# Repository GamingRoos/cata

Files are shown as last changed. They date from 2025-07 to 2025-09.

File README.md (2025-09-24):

# Cata Keyboard

Cata is a 34 key ortholinear keyboard, powered by a [Waveshare RP2040-Zero](https://www.waveshare.com/rp2040-zero.htm).

It uses [Gateron KS-33 Low Profile 3.0 keyswitches](https://nuphy.com/products/gateron-low-profile-3-0-switches) with 19mm x 19mm spacing.

The PCB design is akin to the [Sha Keyboard](https://github.com/skarrmann/sha), but with fewer keys and different keyswitches.

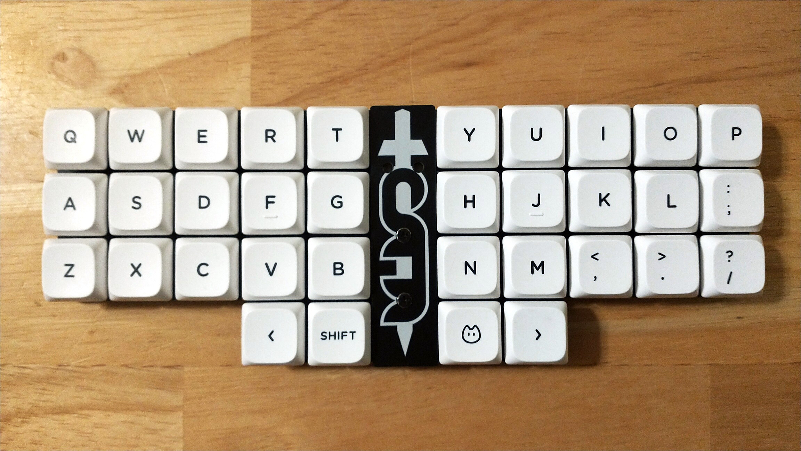
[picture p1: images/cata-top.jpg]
Cata complete build top photo

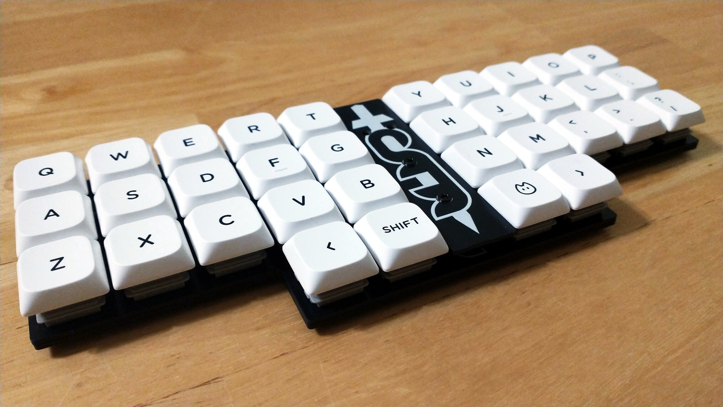
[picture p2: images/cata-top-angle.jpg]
Cata complete build top angle photo

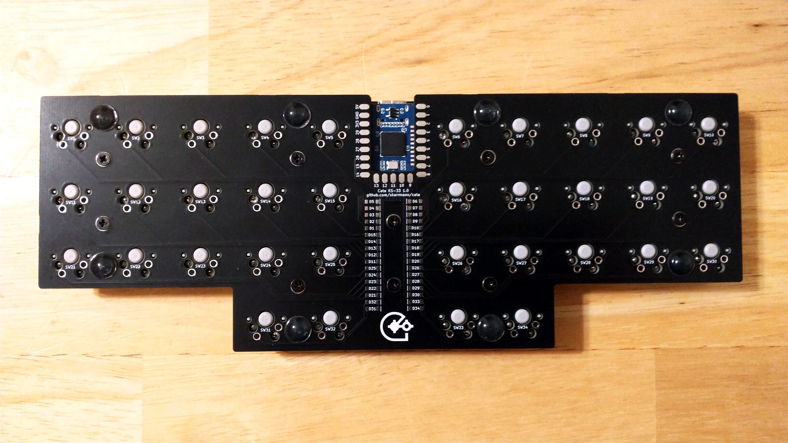
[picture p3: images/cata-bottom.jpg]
Cata complete build bottom photo

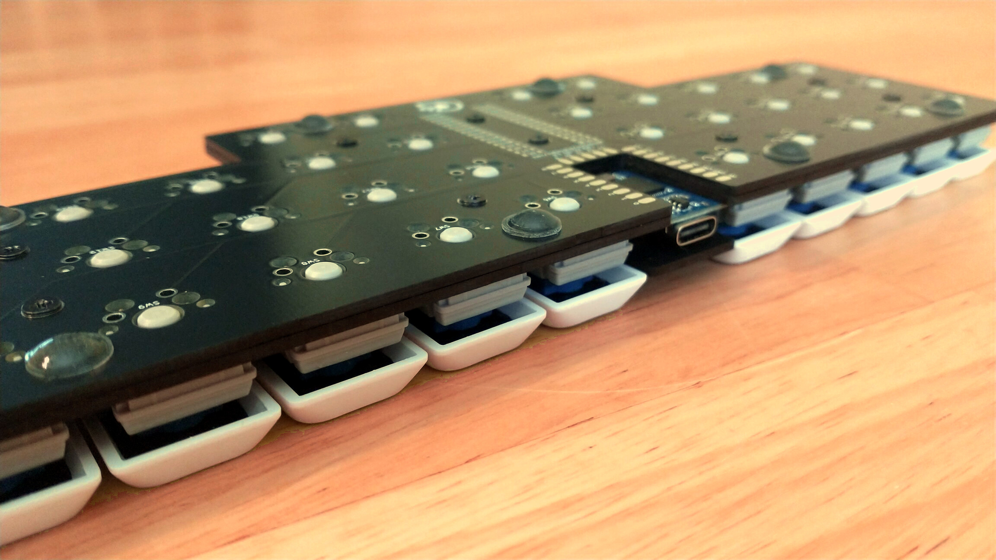
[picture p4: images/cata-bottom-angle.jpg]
Cata complete build bottom angle photo


## Project structure

* [`gerbers`](gerbers): Gerber files for PCB manufacturing
* [`graphics`](graphics): Source assets for PCB silkscreen
* [`kicad`](kicad): KiCad project files (schematics and PCB designs)
* [`kicad-libraries`](kicad-libraries): KiCad components and footprints
* [`images`](images): Images for project documentation

## PCBs

**Each build uses two copies of the main PCB and one copy of the top plate PCB.**

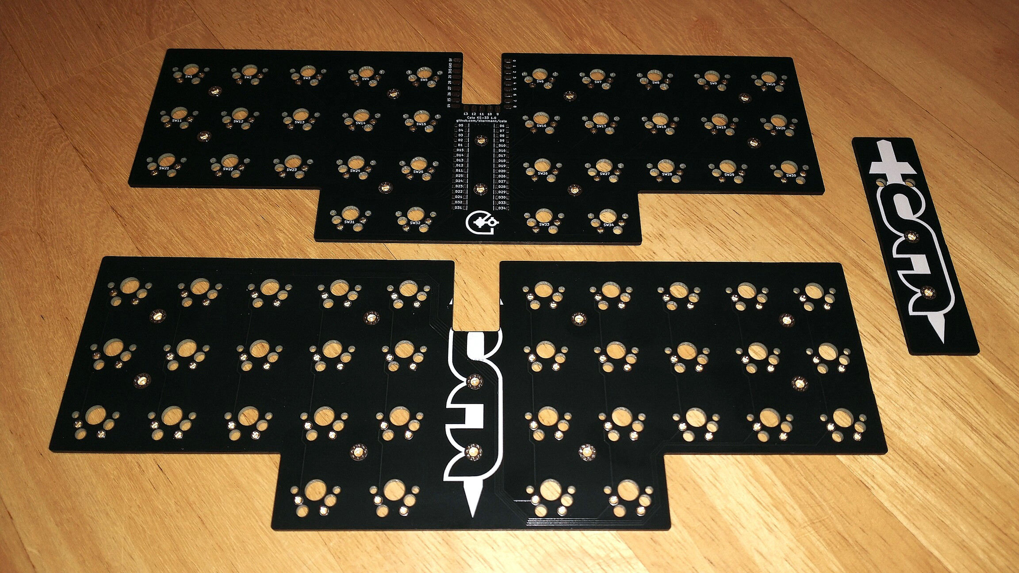
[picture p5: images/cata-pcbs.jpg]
Cata PCBs photo


The main PCB is used as the logical PCB. A second copy of the main PCB is used a bottom plate, by flipping it the long way and screwing it directly to the logical PCB.

The plate PCB cover the dev board and diodes. It has cutouts which fit the boot and reset buttons on the dev board.

## Keyboard firmware

* KMK
    * Setup instructions and basic configuration is in this repo: [`firmware/kmk`](firmware/kmk)
* [QMK](https://github.com/qmk/qmk_firmware/tree/master/keyboards/cata)
* QMK/VIAL VIAL configs here: [`firmware/vial`](firmware/vial)
## Bill of materials

Part | Purpose | Quantity | Notes
---- | ------- | -------- | ---------
Main PCB  | logical PCB, bottom plate | 2 | Send Gerber zip files to [JLCPCB](https://jlcpcb.com/)
Top plate PCB  | cover dev board and diodes  | 1 | 
Waveshare RP2040-Zero | Microcontroller board | 1 |
1N4148 SOD-123 | Diodes for keyboard row-column matrix | 34 |
Gateron KS-33 Low Profile 3.0 Keyswitches |  | 34 | [Several options available from Nuphy](https://nuphy.com/products/gateron-low-profile-3-0-switches)
MX Low Profile Keycaps | | 34 | Use low profile keycaps which fit 19mm x 19mm spacing
M2 5mm screws | Screws PCBs together | 12 |
M2 6mm spacers | Spacers between logical PCB and top plates | 2 |
M2 nuts | Holds the top screws between the bottom plate and logical PCB | 8 |

## PCB manufacturing settings

These are the manufacturing settings I used when ordering from JLCPCB:

* **Base Material**: FR4
* **Layers**: 2
* **Dimensions**: (whatever the gerber file specifies)
* **PCB Qty**: 5
* **Different Design**: 1
* **Delivery Format**: Single PCB
* **PCB Thickness**: 1.6
* **PCB Color**: Black
* **Silkscreen**: White
* **Surface Finish**: LeadFree HASL-RoHS
* **Outer Copper Weight**: 1 oz
* **Gold Fingers**: No
* **Confirm Production File**: No
* **Flying Probe Test**: Fully Test
* **Castellated Holes**: No
* **Mark on PCB**: Remove Mark

## Build tips

* Before starting, check if the PCBs are warped, and bend them to be perfectly flat before soldering.
* Make sure the diodes are oriented correctly, cathode on the side with the line! The diodes are very close together, so narrow tweasers can help position them.
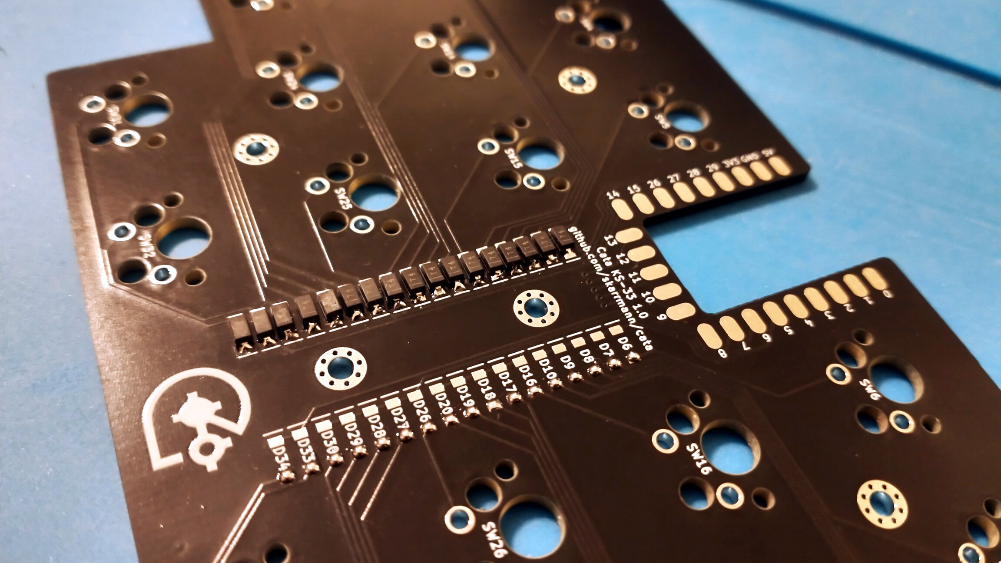
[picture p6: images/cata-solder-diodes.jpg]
Cata soldering diodes photo
    * 
* Make sure the RP2040-Zero is soldered **buttons on top**. The pinout labels printed on the PCB should align with those printed on the dev board.
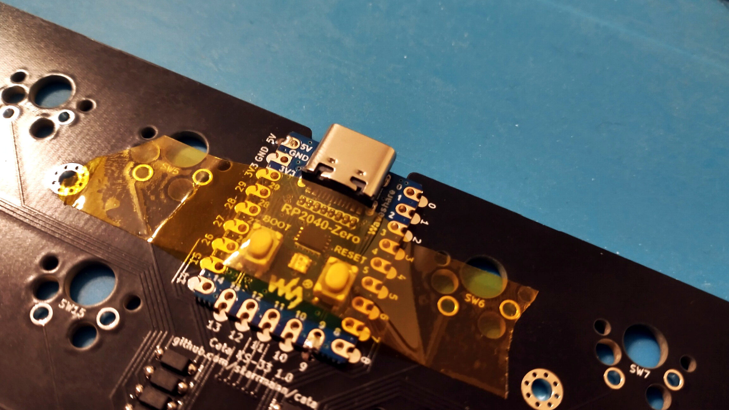
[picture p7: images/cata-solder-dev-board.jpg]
Cata soldering dev board photo
    * 
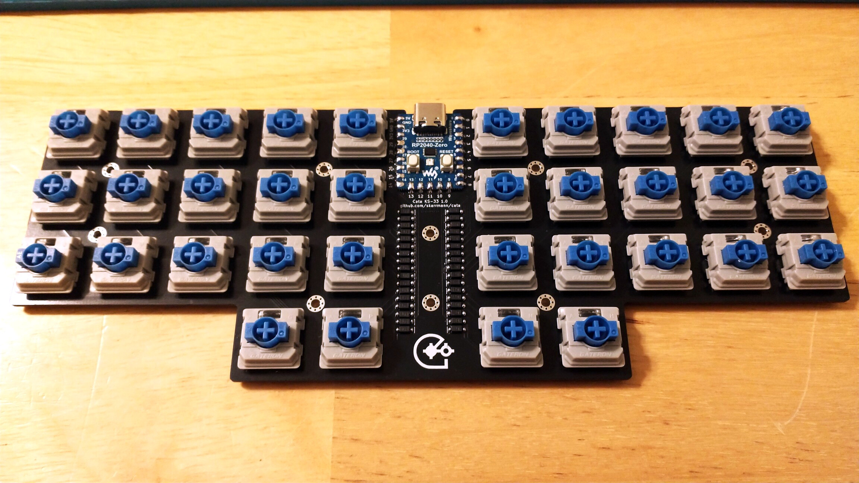
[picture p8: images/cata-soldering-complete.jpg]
Cata soldering complete photo
    * 

## KiCad project notes

The top plate was generated with the [Horizon Board Producer KiCad plugin](https://github.com/skarrmann/horizon#kicad-project-notes).

## Revision history

* Cata 1.0 (2025-07-27)
    * Initial Gateron KS-33 Low Profile 3.0 switch PCB design

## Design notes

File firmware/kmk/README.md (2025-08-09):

# Cata KMK Firmware

## Installation instructions

1. Install CircuitPython:
    * https://circuitpython.org/board/waveshare_rp2040_zero/
2. Copy KMK firmware files:
    * https://github.com/KMKfw/kmk_firmware/blob/master/docs/en/Getting_Started.md
3. Copy the custom files:
    * [`kb.py`](kb.py)
    * [`main.py`](main.py)
    * [`oneshot_mod.py`](oneshot_mod.py)

Now customize the layout and features in [`main.py`](main.py) file, and save the updates on your board.

## Default keymap

View the [Janus default keymap on Keyboard Layout Editor](http://www.keyboard-layout-editor.com/#/gists/5144ea6a6c998df5f502f9240068de80)

This default keymap is inspired by [Callum's QMK keymap](https://github.com/qmk/qmk_firmware/tree/master/users/callum), with the following differences:

* Mods are moved to the bottom row on every layer, and are mirrored on both sides.
* Symbol layer only contains non-shifted symbol keys.
* General differences in key positions.

Both layouts use similar oneshot key implementations.

## Custom oneshot module

As part of the oneshot module's setup, the following two methods should be called:

* `set_ignore_keys(ignore_keys)`: Specify a list of keys which are not treated as oneshot interrupt keys

Oneshot keys behave as follows:

* When a oneshot key is pressed:
    * Set oneshot status as "active"
    * Send a key press event for its corresponding key
* When a oneshot key is released:
    * If oneshot status is "active", then set this oneshot key's status as "queued"
    * If oneshot status is not "active", send a key release event for its corresponding key
* When an interrupt key (i.e., not a oneshot key and not an ignored key) is pressed:
    * Set oneshot status as "inactive"
    * For every oneshot key with status "queued", send key release event for their corresponding key
    * Clear all oneshot key statuses

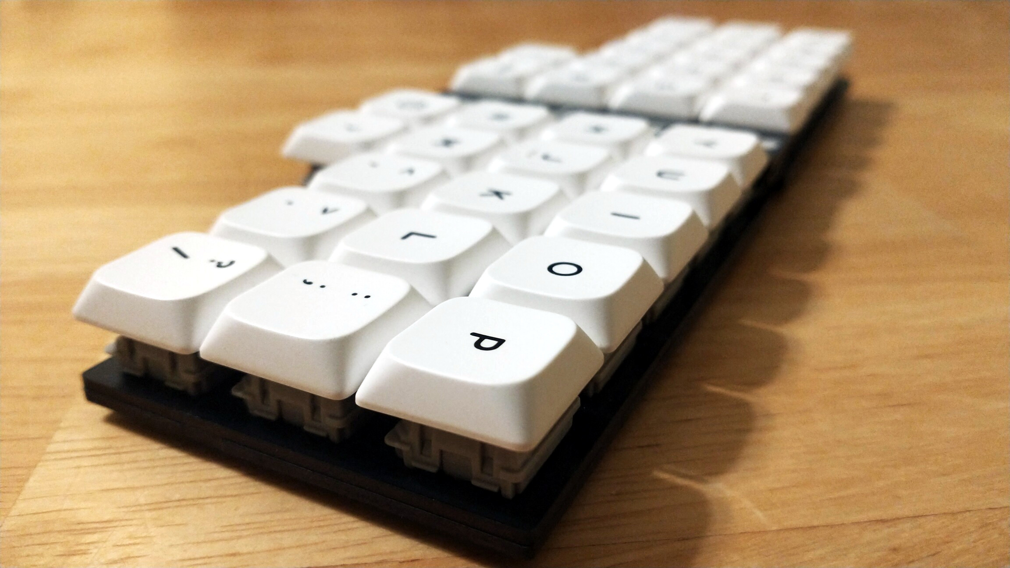
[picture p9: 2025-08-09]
images/cata-top-angle-close.jpg

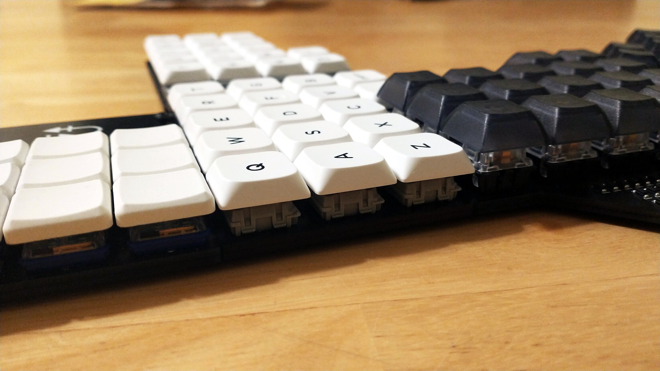
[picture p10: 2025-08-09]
images/cata-key-height-choc-mx.jpg

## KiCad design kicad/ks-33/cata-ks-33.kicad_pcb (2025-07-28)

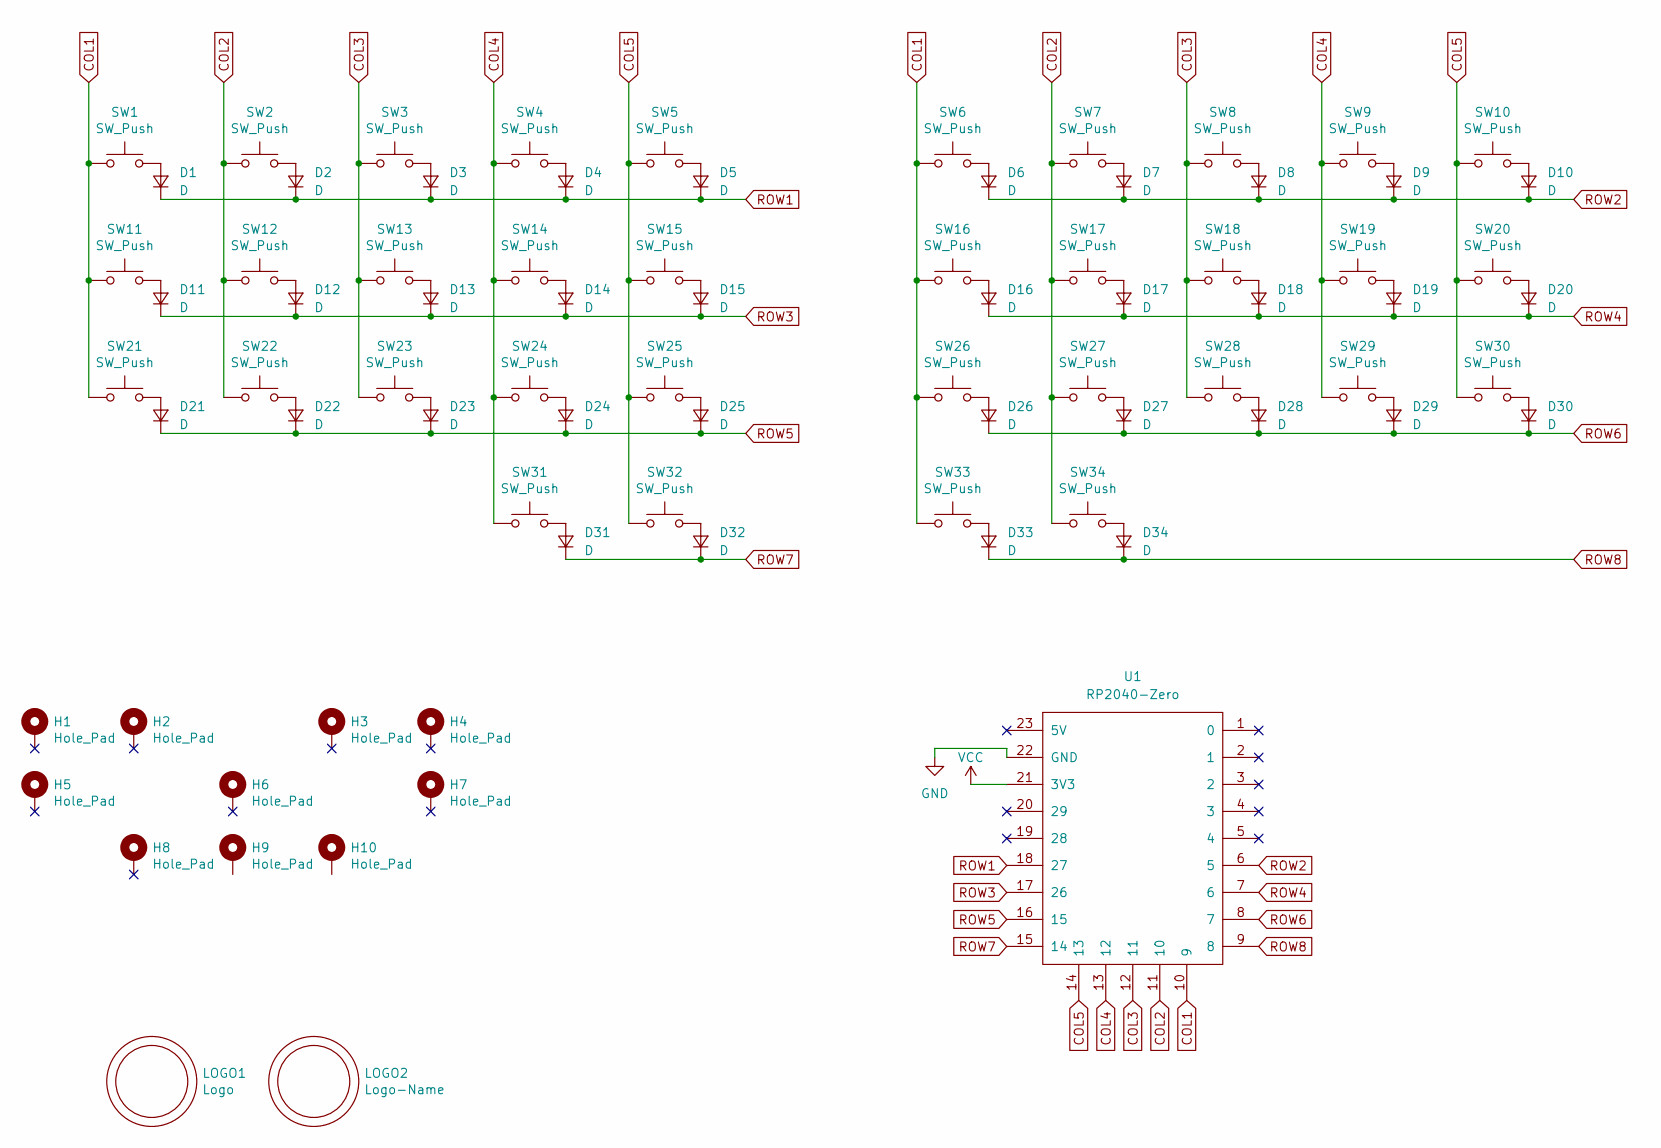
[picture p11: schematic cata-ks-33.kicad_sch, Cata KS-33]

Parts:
D1, D2, D3, D4, D5, D6, D7, D8, D9, D10, D11, D12, D13, D14, D15, D16, D17, D18, D19, D20, D21, D22, D23, D24, D25, D26, D27, D28, D29, D30, D31, D32, D33, D34: D; D_SOD-123
H1, H2, H3, H4, H5, H6, H7, H8, H9, H10: Hole_Pad; Mount_M2
LOGO1: Logo; Logo_Cata
LOGO2: Logo-Name; Logo_Cata_Name
SW1, SW2, SW3, SW4, SW5, SW6, SW7, SW8, SW9, SW10, SW11, SW12, SW13, SW14, SW15, SW16, SW17, SW18, SW19, SW20, SW21, SW22, SW23, SW24, SW25, SW26, SW27, SW28, SW29, SW30, SW31, SW32, SW33, SW34: SW_Push; SW_KS33_Reverse_Cutout
U1: RP2040-Zero; RP2040-Zero_SMD

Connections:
COL1: SW1.1, SW6.1, SW11.1, SW16.1, SW21.1, SW26.1, SW33.1, U1.10 (9)
COL2: SW2.1, SW7.1, SW12.1, SW17.1, SW22.1, SW27.1, SW34.1, U1.11 (10)
COL3: SW3.1, SW8.1, SW13.1, SW18.1, SW23.1, SW28.1, U1.12 (11)
COL4: SW4.1, SW9.1, SW14.1, SW19.1, SW24.1, SW29.1, SW31.1, U1.13 (12)
COL5: SW5.1, SW10.1, SW15.1, SW20.1, SW25.1, SW30.1, SW32.1, U1.14 (13)
GND: U1.22 (GND)
unnamed: D1.2 (A), SW1.2
unnamed: D2.2 (A), SW2.2
unnamed: D3.2 (A), SW3.2
unnamed: D4.2 (A), SW4.2
unnamed: D5.2 (A), SW5.2
unnamed: D6.2 (A), SW6.2
unnamed: D7.2 (A), SW7.2
unnamed: D8.2 (A), SW8.2
unnamed: D9.2 (A), SW9.2
unnamed: D10.2 (A), SW10.2
unnamed: D11.2 (A), SW11.2
unnamed: D12.2 (A), SW12.2
unnamed: D13.2 (A), SW13.2
unnamed: D14.2 (A), SW14.2
unnamed: D15.2 (A), SW15.2
unnamed: D16.2 (A), SW16.2
unnamed: D17.2 (A), SW17.2
unnamed: D18.2 (A), SW18.2
unnamed: D19.2 (A), SW19.2
unnamed: D20.2 (A), SW20.2
unnamed: D21.2 (A), SW21.2
unnamed: D22.2 (A), SW22.2
unnamed: D23.2 (A), SW23.2
unnamed: D24.2 (A), SW24.2
unnamed: D25.2 (A), SW25.2
unnamed: D26.2 (A), SW26.2
unnamed: D27.2 (A), SW27.2
unnamed: D28.2 (A), SW28.2
unnamed: D29.2 (A), SW29.2
unnamed: D30.2 (A), SW30.2
unnamed: D31.2 (A), SW31.2
unnamed: D32.2 (A), SW32.2
unnamed: D33.2 (A), SW33.2
unnamed: D34.2 (A), SW34.2
ROW1: D1.1 (K), D2.1 (K), D3.1 (K), D4.1 (K), D5.1 (K), U1.18 (27)
ROW2: D6.1 (K), D7.1 (K), D8.1 (K), D9.1 (K), D10.1 (K), U1.6 (5)
ROW3: D11.1 (K), D12.1 (K), D13.1 (K), D14.1 (K), D15.1 (K), U1.17 (26)
ROW4: D16.1 (K), D17.1 (K), D18.1 (K), D19.1 (K), D20.1 (K), U1.7 (6)
ROW5: D21.1 (K), D22.1 (K), D23.1 (K), D24.1 (K), D25.1 (K), U1.16 (15)
ROW6: D26.1 (K), D27.1 (K), D28.1 (K), D29.1 (K), D30.1 (K), U1.8 (7)
ROW7: D31.1 (K), D32.1 (K), U1.15 (14)
ROW8: D33.1 (K), D34.1 (K), U1.9 (8)
VCC: U1.21 (3V3)

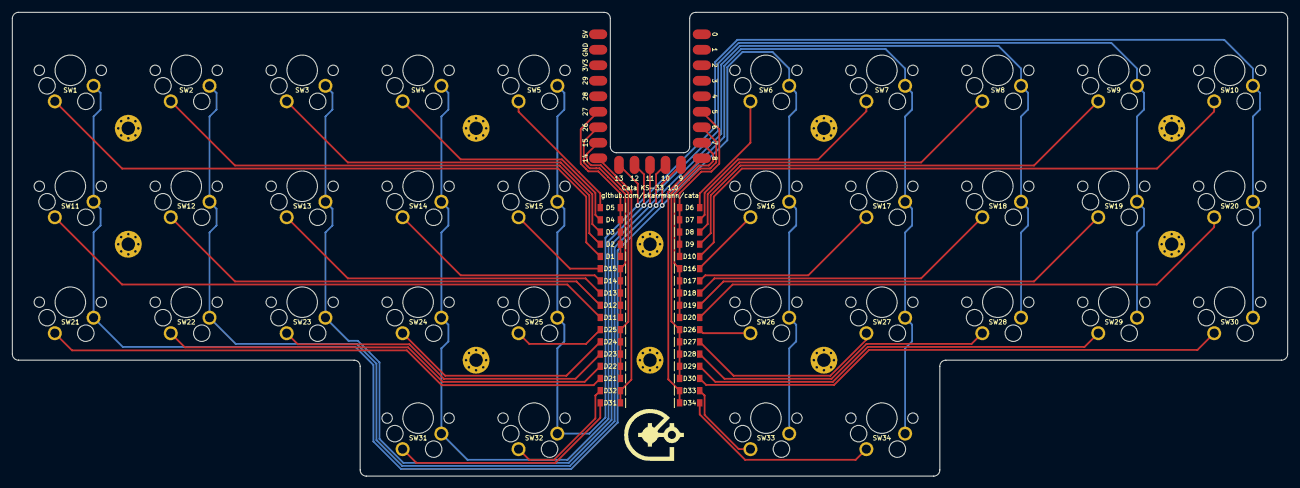
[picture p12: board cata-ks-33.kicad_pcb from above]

Board: 2 copper layers, 209.0 x 76.0 mm, 81 parts (1 on the bottom side), 47 nets.

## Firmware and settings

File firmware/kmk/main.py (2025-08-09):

from kb import KMKKeyboard
from kmk.keys import KC
from kmk.modules.layers import Layers
from kmk.extensions.media_keys import MediaKeys
from kmk.extensions.international import International
from oneshot import OneShot


keyboard = KMKKeyboard()

layers_ext = Layers()
oneshot_ext = OneShot()
media_keys = MediaKeys()
international = International()

keyboard.modules = [layers_ext, oneshot_ext]
keyboard.extensions = [media_keys, international]

SYM = KC.MO(1)
NAV = KC.MO(2)
FUN = KC.MO(3)

OS_LCTL = KC.OS(KC.LCTL)
OS_LSFT = KC.OS(KC.LSFT)
OS_LALT = KC.OS(KC.LALT)
OS_LGUI = KC.OS(KC.LGUI)
OS_RCTL = KC.OS(KC.RCTL)
OS_RSFT = KC.OS(KC.RSFT)
OS_RALT = KC.OS(KC.RALT)
OS_RGUI = KC.OS(KC.RGUI)

oneshot_ext.set_ignore_keys([SYM, NAV, FUN])

keyboard.keymap = [
    [   # Default
        KC.Q,    KC.W,    KC.F,    KC.P,    KC.G,    KC.J,    KC.L,    KC.U,    KC.Y,    KC.QUOT,
        KC.A,    KC.R,    KC.S,    KC.T,    KC.D,    KC.H,    KC.N,    KC.E,    KC.I,    KC.O,
        KC.Z,    KC.X,    KC.C,    KC.V,    KC.B,    KC.K,    KC.M,    KC.COMM, KC.DOT,  KC.SLSH,
                                   NAV,     KC.LSFT, KC.SPC,  SYM
    ],
    [   # Symbol
        KC.SCLN, KC.LBRC, KC.RBRC, KC.N5,   KC.NO,   KC.NO,   KC.N6,   KC.MINS, KC.EQL,  KC.GRV,
        KC.N1,   KC.N2,   KC.N3,   KC.N4,   KC.BSLS, KC.NO,   KC.N7,   KC.N8,   KC.N9,   KC.N0,
        OS_LGUI, OS_LALT, OS_LSFT, OS_LCTL, KC.NO,   KC.NO,   OS_RCTL, OS_RSFT, OS_RALT, OS_RGUI,
                                   FUN,     KC.TRNS, KC.TRNS, KC.TRNS
    ],
    [   # Navigation
        KC.PSCR, KC.INS,  KC.APP,  KC.DEL,  KC.NO,   KC.NO,   KC.HOME, KC.PGDN, KC.PGUP, KC.END,
        KC.ESC,  KC.TAB,  KC.ENT,  KC.BSPC, KC.NO,   KC.PAUS, KC.LEFT, KC.DOWN, KC.UP,   KC.RGHT,
        OS_LGUI, OS_LALT, OS_LSFT, OS_LCTL, KC.NO,   KC.NO,   OS_RCTL, OS_RSFT, OS_RALT, OS_RGUI,
                                   KC.TRNS, KC.TRNS, KC.TRNS, FUN
    ],
    [   # Function
        KC.F1,   KC.F2,   KC.F3,   KC.F4,   KC.NO,   KC.SLCK, KC.MPLY, KC.MPRV, KC.MNXT, KC.BRIU,
        KC.F5,   KC.F6,   KC.F7,   KC.F8,   KC.NO,   KC.CLCK, KC.MUTE, KC.VOLD, KC.VOLU, KC.BRID,
        KC.F9,   KC.F10,  KC.F11,  KC.F12,  KC.NO,   KC.NLCK, OS_RCTL, OS_RSFT, OS_RALT, OS_RGUI,
                                   KC.TRNS, KC.TRNS, KC.TRNS, KC.TRNS
    ]
]

if __name__ == '__main__':
    keyboard.go()

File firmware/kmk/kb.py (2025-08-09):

import board
from kmk.kmk_keyboard import KMKKeyboard as _KMKKeyboard
from kmk.scanners import DiodeOrientation


class KMKKeyboard(_KMKKeyboard):
    def __init__(self):
        super().__init__()

        self.col_pins = (board.GP9, board.GP10, board.GP11, board.GP12, board.GP13)
        self.row_pins = (board.GP27, board.GP5, board.GP26, board.GP6, board.GP15, board.GP7, board.GP14, board.GP8)
        self.diode_orientation = DiodeOrientation.COLUMNS

        self.coord_mapping = [
             0,  1,  2,  3,  4,  5,  6,  7,  8,  9,
            10, 11, 12, 13, 14, 15, 16, 17, 18, 19,
            20, 21, 22, 23, 24, 25, 26, 27, 28, 29,
                         33, 34, 35, 36
        ]

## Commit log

2025-07-28 Fix diode alignment, generate gerbers
    [cata-ks-33.kicad_pcb]
2025-07-28 Move logo and name silkscreen on PCB
    [cata-ks-33.kicad_pcb]
